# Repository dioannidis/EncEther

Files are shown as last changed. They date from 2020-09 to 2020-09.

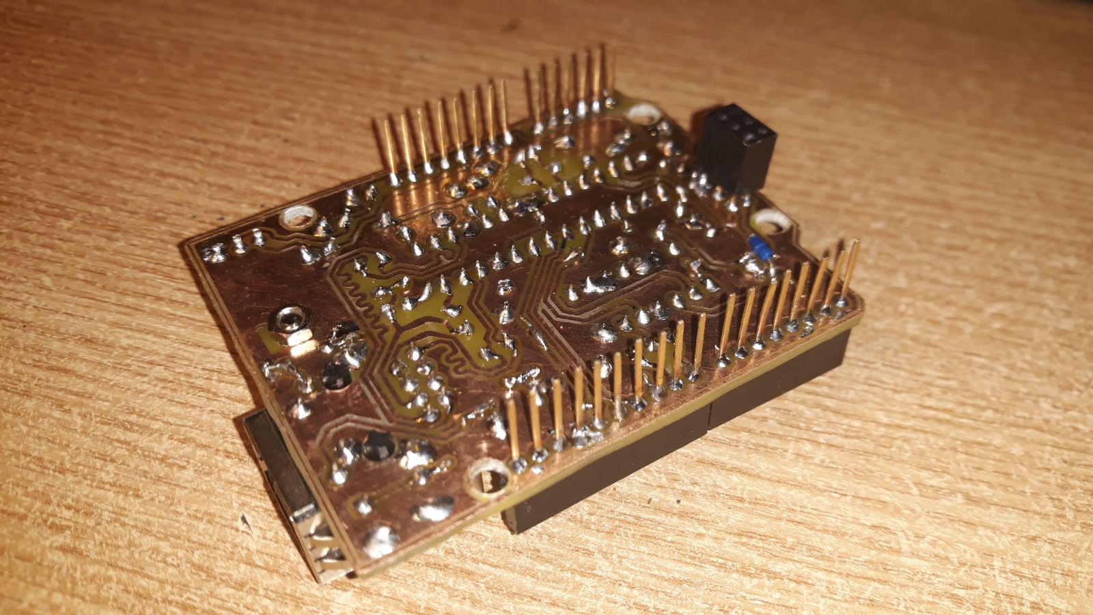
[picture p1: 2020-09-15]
IMAGES/EncEther-v1-bottom.jpg

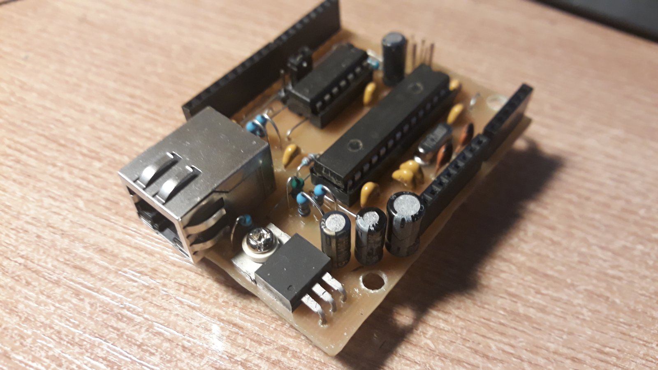
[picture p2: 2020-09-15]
IMAGES/EncEther-v1-top.jpg

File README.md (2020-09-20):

# EncEther

( version 3 )

   A single side, through hole, Arduino ethernet shield, designed in Kicad 5. 



### Main IC's

   * ENC28J60        10Base-T stand-alone ethernet controller
   * SN74HCT125N     3 state quadruple buffer for level shifting

   ( all the components datasheets can be found in the DATASHEETS directory )

### Board Info / Tips

   * As a single side board jumper wires are hard to avoid. Currently, exists 16 jumper wires, which are to be soldered first.
   * The L1 4μH inductor, is for EMC ( as per datasheet ), so you can replace it with a jumper wire.
   * The R3, R4, R11 and R12 are 49.9 Ω 1% 1/4W resistors ( as per datasheet ) but I'm using 51 Ω 1% 1/4W with success. The 49.9 Ω 1% ones are hard to find ( at least I can't find them easily ).
   * Because some jumper wires are routed under the sockets, use precision sockets which have more room under them.
   * The MagJack I use is the LMJTAB881243ML from AMPHENOL. You can find it at [TME](https://www.tme.eu/en/details/lmjtab881243m-l/rj-connectors/amphenol/lmjtab881243ml) or at [Grobotronics](https://grobotronics.com/rj45-ethernet-magjack-compatible.html) ( cheaper ).
   * The wakeup and clkout pins of ENC28J60 are not exposed. As this is an UNO shield, there is no need to provide clock to the MCU, it has it's own. And AFAIK, UIPEthernet doesn't implement the wakeup function.

### Board Configuration 

   * Jumper J3

      The CS/SS ( chip select / slave select ) signal can be connected to Arduino Pin 10 or Pin 9 using the J3 jumper.

         * Jumper on the 1-2 pins connects CS/SS to Arduino Pin 10. ( default )
         * Jumper on the 2-3 pins connects CS/SS to Arduino Pin 9.

      The Interrupt pin from the ENC28J60 it can be connected to Arduino Pin 9 or Pin 8 using the J3 jumper.

         * Jumper on the 3-4 pins connects the ENC28J60's interrupt pin to Arduino Pin 9.
         * Jumper on the 4-5 pins connects the ENC28J60's interrupt pin to Arduino Pin 8.

      Optionally, you can populate the U4 socket with an AT24MAC402-602 on a 8-Pin SOIC to DIP adapter ( something like [this](https://www.sparkfun.com/products/13655) or [this](https://www.adafruit.com/product/1212) ) to have a legit MAC Address and an extra 2Kbit serial EEPROM.

   * Jumper J4

      The I2C address of the AT24MAC402-602 can be selected using Jumper J3 as :
		
         * Jumper on 2-3 pins address is 0. ( default )
         * Jumper on 1-2 pins address is 1.

### Examples

( in EXAMPLES directory. Of course the examples work with any ENC28J60 board / module. )

   * EthernetRest 
	  
      Uses the UIPEthernet and aRest libraries.
	   
      Using the aRest API you can control all digital and analog pins and / or executing custom functions or read custom variables.

### Gallery

   Those pictures are from v1. It didn't have the AT24MAC402-602 option and the CS/SS Pin selection designed yet.




   As you can see in the picture below, the AT24MAC402, is on the small red 8-Pin SOIC to DIP adapter on the breadboard.



-----

Copyright © 2020 Dimitrios Chr. Ioannidis

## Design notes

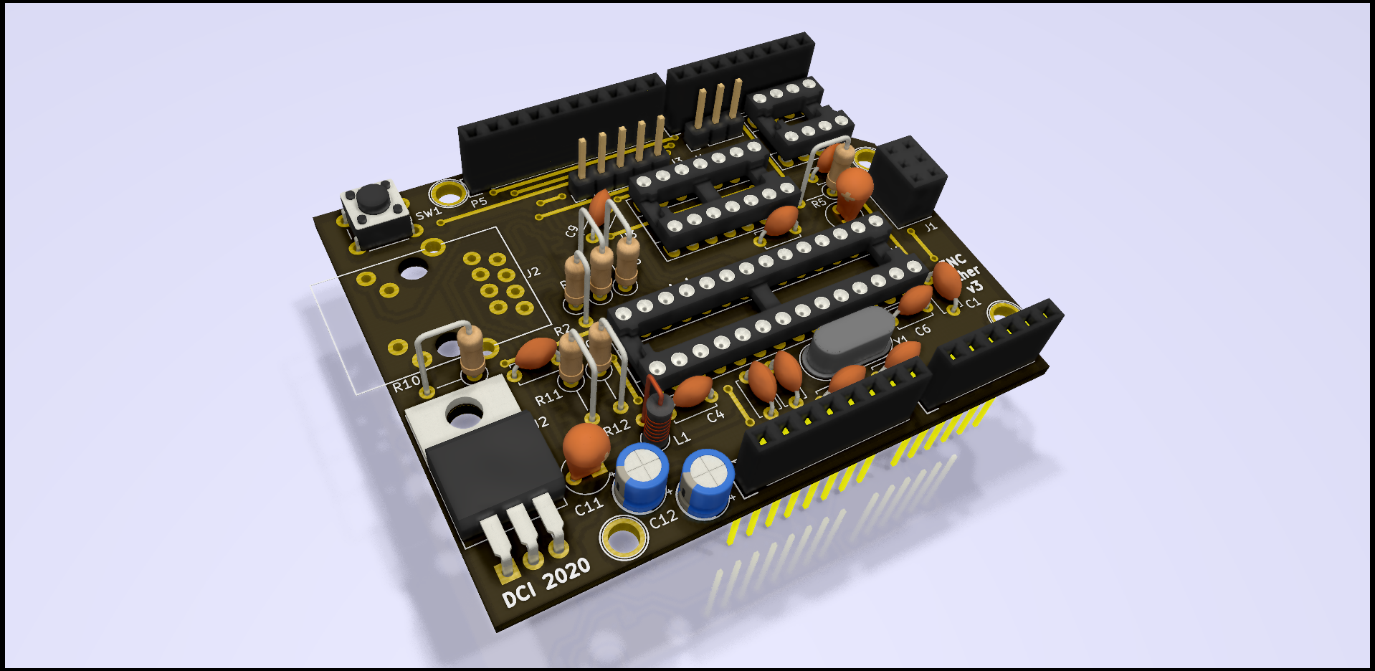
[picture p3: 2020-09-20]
IMAGES/enc28j60_buffered_tht_shield.png

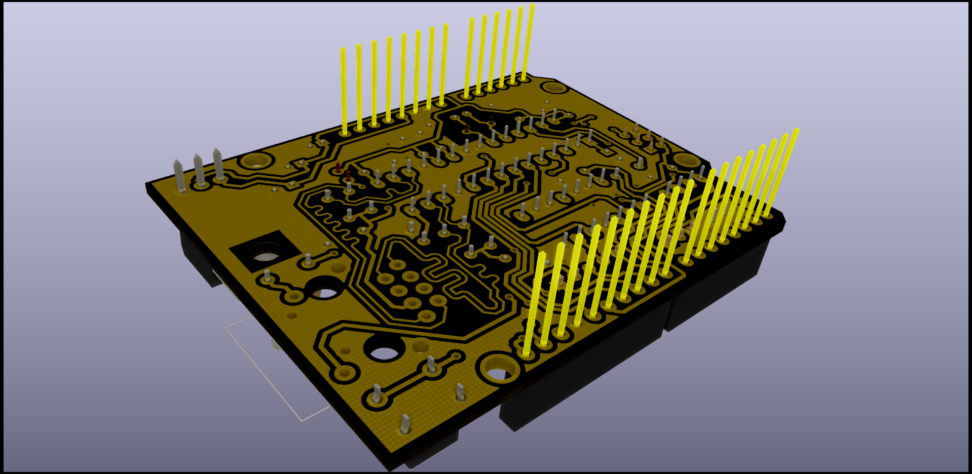
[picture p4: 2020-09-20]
IMAGES/enc28j60_buffered_tht_shield_bottom.png

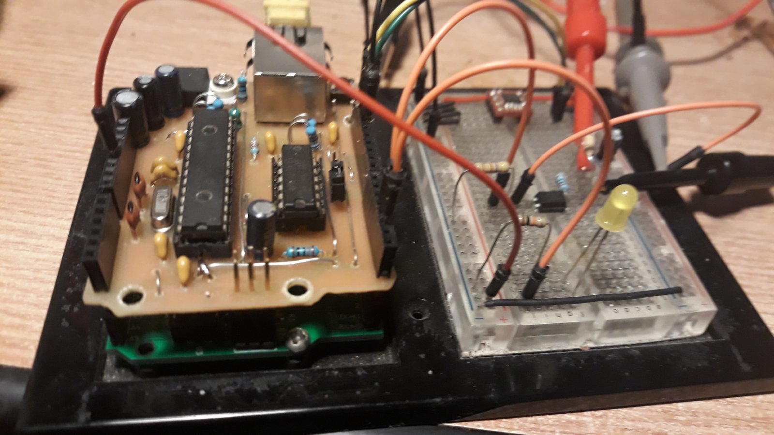
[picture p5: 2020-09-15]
IMAGES/EncEther-v1-uno.jpg

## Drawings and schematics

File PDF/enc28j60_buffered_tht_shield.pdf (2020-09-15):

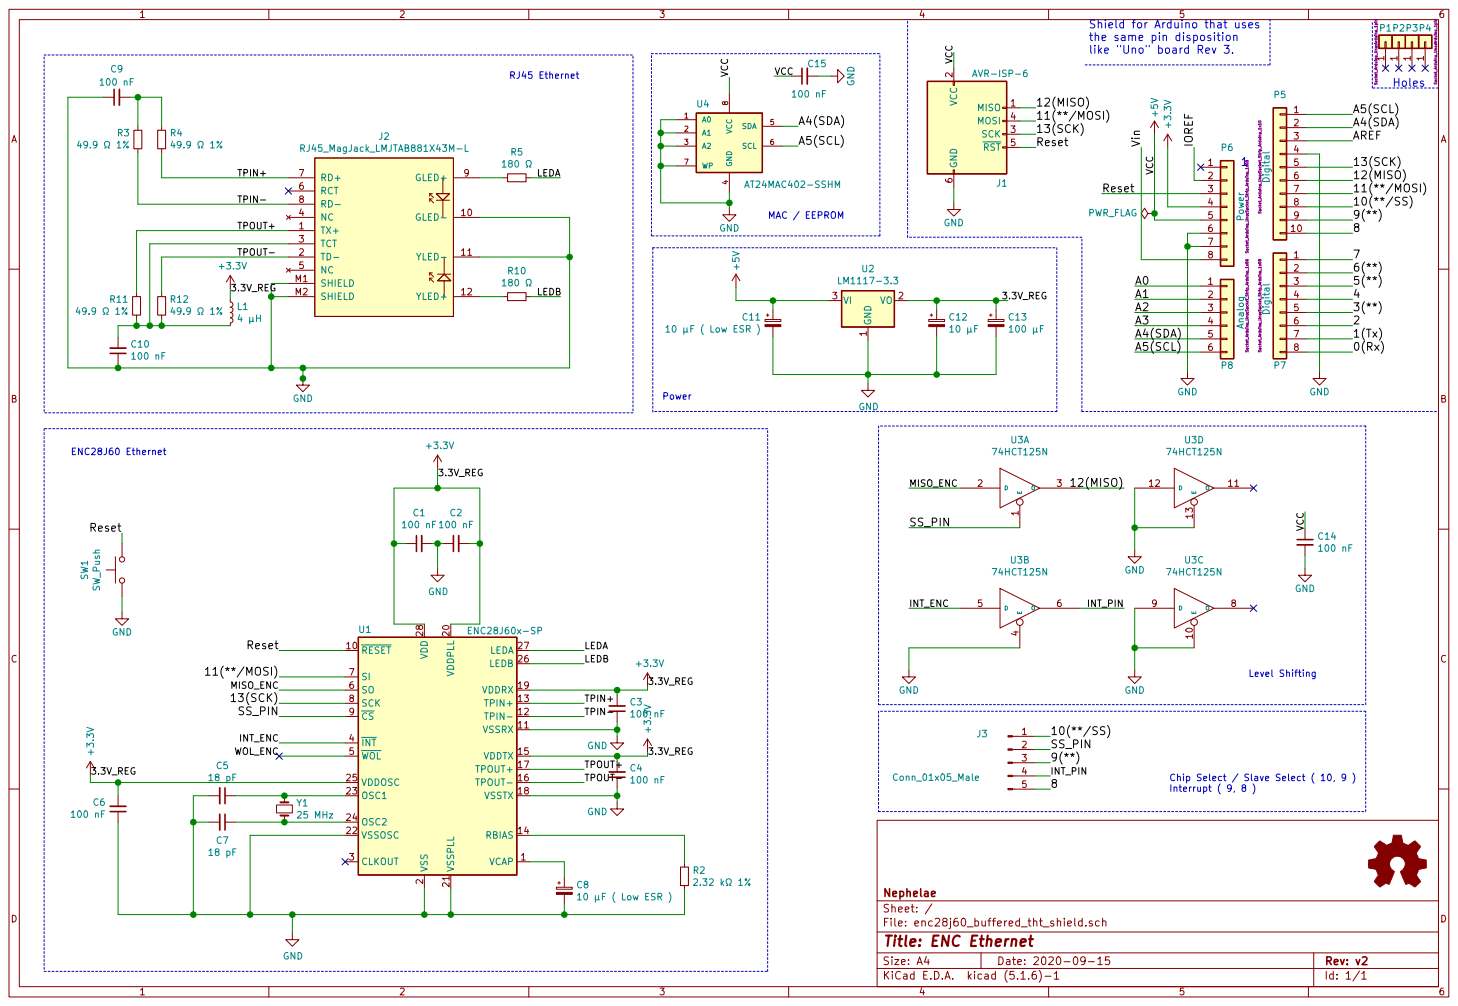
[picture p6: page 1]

the same pin disposition

2 SCK 3 MOSI 4 RST 5 GND

4 SDA 5 SCL 6 WP 7 VCC U4 8 AT24MAC402-SSHM

2 VDDPLL 20 VSSPLL 21 VSSOSC 22 OSC1 23 OSC2 24 VDDOSC 25

Chip Select / Slave Select ( 10, 9 )

Id: 1/1 Title: ENC Ethernet

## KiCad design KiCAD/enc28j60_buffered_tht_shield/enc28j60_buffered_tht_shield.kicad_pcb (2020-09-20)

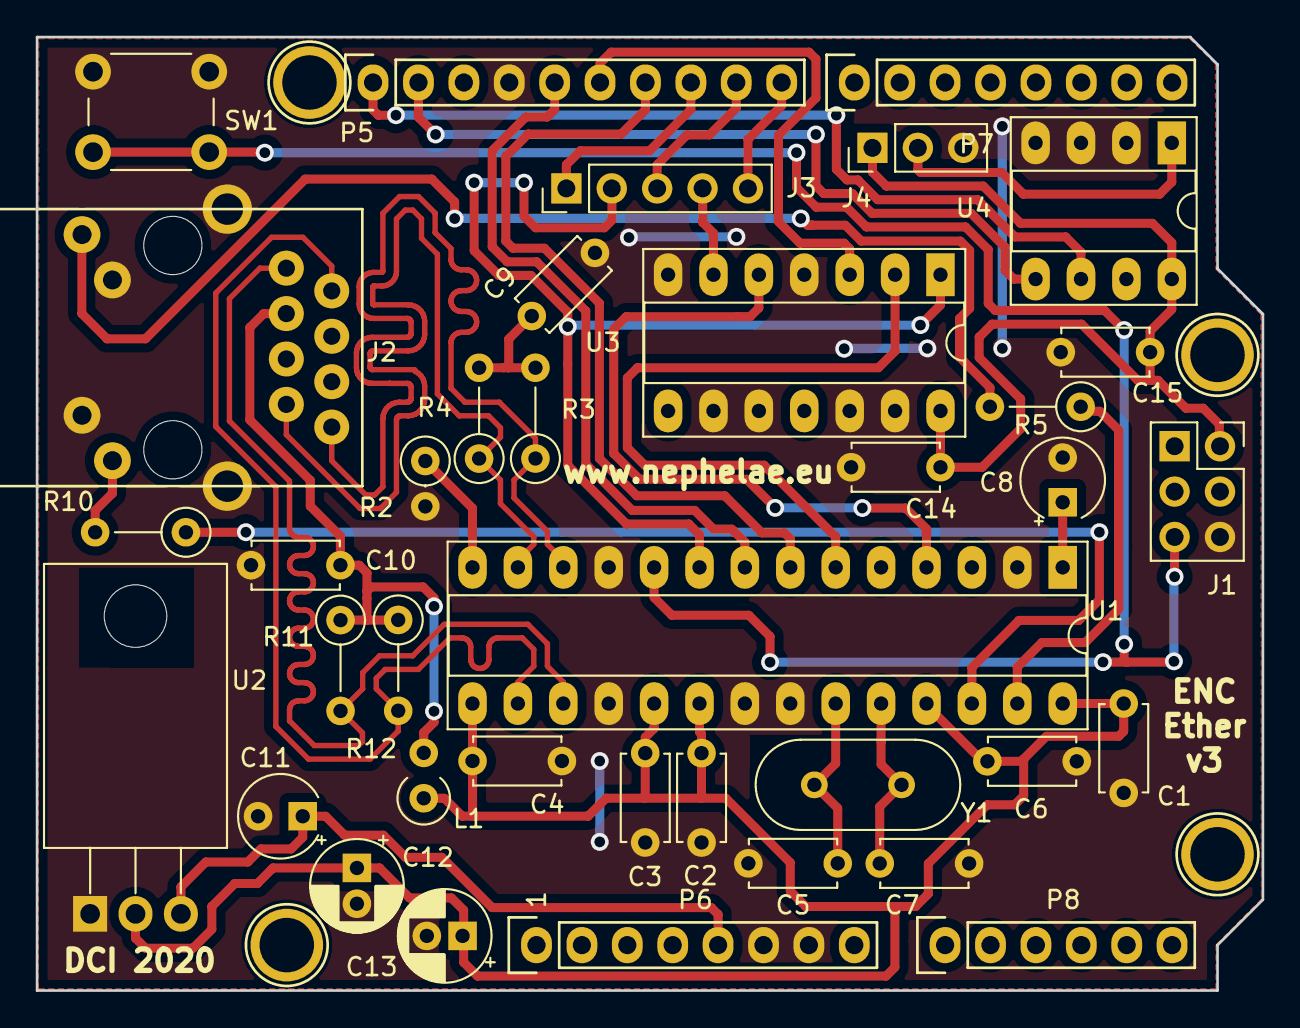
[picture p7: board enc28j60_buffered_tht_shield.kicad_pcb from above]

Board: 2 copper layers, 68.6 x 53.3 mm, 41 parts (0 on the bottom side), 32 nets.

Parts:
C1, C2, C3, C4, C6, C9, C10, C14, C15: 100 nF; C_Disc_D4.7mm_W2.5mm_P5.00mm
C5, C7: 18 pF; C_Disc_D4.7mm_W2.5mm_P5.00mm
C8, C11: 10 μF ( Low ESR ); CP_Radial_Tantal_D4.5mm_P2.50mm
C12: 10 μF; CP_Radial_D5.0mm_P2.00mm
C13: 100 μF; CP_Radial_D5.0mm_P2.00mm
J1: AVR-ISP-6; PinSocket_2x03_P2.54mm_Vertical
J2: RJ45_MagJack_LMJTAB881X43M-L
J3: Conn_01x05_Male; PinHeader_1x05_P2.54mm_Vertical
J4: Conn_01x03_Male; PinHeader_1x03_P2.54mm_Vertical
L1: 4 μH; L_Axial_L6.6mm_D2.7mm_P2.54mm_Vertical_Vishay_IM-2
P1, P2, P3, P4: CONN_01X01; Arduino_1pin
P5: Digital; Socket_Strip_Arduino_1x10
P6: Power; Socket_Strip_Arduino_1x08
P7: Digital; Socket_Strip_Arduino_1x08
P8: Analog; Socket_Strip_Arduino_1x06
R2: 2.32 kΩ 1%; R_Axial_DIN0207_L6.3mm_D2.5mm_P2.54mm_Vertical
R3, R4, R11, R12: 49.9 Ω 1%; R_Axial_DIN0207_L6.3mm_D2.5mm_P5.08mm_Vertical
R5, R10: 180 Ω; R_Axial_DIN0207_L6.3mm_D2.5mm_P5.08mm_Vertical
SW1: SW_Push; SW_PUSH_6mm_H5mm
U1: ENC28J60x-SP; DIP-28_W7.62mm_Socket_LongPads
U2: LM1117-3.3; TO-220-3_Horizontal_TabDown
U3: 74HCT125N; DIP-14_W7.62mm_Socket_LongPads
U4: AT24MAC402-SSHM; DIP-8_W7.62mm_Socket_LongPads
Y1: 25 MHz; Crystal_HC49-4H_Vertical

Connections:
+3V3: C1.1, C2.2, C3.2, C4.2, C6.2, C12.1, C13.1, L1.1, U1.15, U1.19, U1.20, U1.25, U1.28, U2.2
+5V: C11.1, P6.5, U2.3
/8: J3.5, P5.10
/9(**): J3.3, P5.9
/10(**/SS): J3.1, P5.8
/11(**/MOSI): P5.7, U1.7
/12(MISO): P5.6, U3.3
/13(SCK): P5.5, U1.8
/A4(SDA): P5.2, U4.5
/A5(SCL): P5.1, U4.6
/A_A0: J4.2, U4.1
/INT_ENC: U1.4, U3.5
/INT_PIN: J3.4, U3.6
/LEDA: R5.1, U1.27
/LEDB: R10.1, U1.26
/MISO_ENC: U1.6, U3.2
/Reset: J1.5, SW1.2, U1.10
/SS_PIN: J3.2, U1.9, U3.1
/TPIN+: J2.7, R4.1, U1.13
/TPIN-: J2.8, R3.1, U1.12
/TPOUT+: J2.1, R11.2, U1.17
/TPOUT-: J2.2, R12.2, U1.16
GND: C1.2, C2.1, C3.1, C4.1, C5.2, C6.1, C7.2, C8.2, C9.1, C10.1, C11.2, C12.2, C13.2, C14.2, C15.2, J1.6, J2.10, J2.11, J2.M1, J2.M2, J4.3, P5.4, P6.6, P6.7, R2.2, SW1.1, U1.2, U1.11, U1.18, U1.21, U1.22, U2.1, U3.4, U3.7, U3.9, U3.10, U3.12, U3.13, U4.2, U4.3, U4.4
unnamed: C5.1, U1.23, Y1.1
unnamed: C7.1, U1.24, Y1.2
unnamed: C8.1, U1.1
unnamed: C9.2, R3.2, R4.2
unnamed: C10.2, J2.3, L1.2, R11.1, R12.1
unnamed: J2.9, R5.2
unnamed: J2.12, R10.2
unnamed: R2.1, U1.14
VCC: C14.1, C15.1, J1.2, J4.1, U3.14, U4.8

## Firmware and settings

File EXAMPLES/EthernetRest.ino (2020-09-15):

/*
  UIPEthernet and aRest for Arduino UNO example.

  Written in 2020 by Dimitrios Chr. Ioannidis under a GPL license.
*/

// UIPEthernet configuration.

// Edit the <Arduino-Libraries-path>\UIPEthernet\utility\uipethernet-conf.h file
// and change the values as below.

//#define UIP_SOCKET_NUMPACKETS     3
//#define UIP_CONF_MAX_CONNECTIONS  2
//#define UIP_CONF_UDP              1
//#define UIP_CONF_UDP_CONNS        1

#define UIP_CONF_MAX_LISTENPORTS  1
#define UIP_CONF_ARPTAB_SIZE      5
#define UIP_CONF_BUFFER_SIZE      300

// Wire configuration.
#define BUFFER_LENGTH 16

// aREST configuration.
#define LIGHTWEIGHT            0
#define AREST_NUMBER_VARIABLES 0
#define AREST_NUMBER_FUNCTIONS 2
//#define DEBUG_MODE             1

#define ethernet_h_   // For aRest to work with UIPEthernet

// Libraries

#include <UIPEthernet.h>
#include <ethernet_comp.h>
#include <Wire.h>
#include <aREST.h>
#include <avr/wdt.h>

// aREST.h
#define NAME_SIZE     5
#define ID_SIZE       4

// Ethernet server
EthernetServer server(80);

#define pwmPin   3    // The PWM output 
#define relayPin 5    // The Relay
#define ledPin   2

// Create aREST instance
aREST rest = aREST();

// Variables to be exposed to the API
//int temperature;
//int humidity;

// Declare functions to be exposed to the API
int pwmControl(String command);

void setup(void)
{
  //  In case for Opto
  //  digitalWrite(relayPin, HIGH);  //Set pin to OUTPUT to SINK any current
  digitalWrite(relayPin, LOW);

  pinMode(relayPin, OUTPUT);
  pinMode(pwmPin, OUTPUT);       // Pin 3 , PWM 490 Hz

  // Give name & ID to the device (ID should be 6 characters long)
  rest.set_id(F("EncE"));
  rest.set_name(F("001"));
  rest.set_status_led(ledPin);

  // Start Serial
  Serial.begin(9600);

  // Start I2C communication
  Wire.begin();
  Wire.setClock(400000);

  // Enter a MAC address for your controller below.
  byte mac[] = { 0x90, 0xA2, 0xDA, 0x0E, 0xFE, 0x41 };

  // If you have connected a AT24MAC402 uncomment the following
  // to read the MAC address parts from the EEPROM into mymac
  
  // readMacAddress(0x0, mac);

  // Init variables and expose them to REST API
  //  temperature = 24;
  //  humidity = 40;
  //  rest.variable("temperature",&temperature);
  //  rest.variable("humidity",&humidity);

  // Function to be exposed
  rest.function("pwm", pwmControl);

  // Start the Ethernet connection and the server
  if (Ethernet.begin(mac) == 0) {
    Serial.println(F("Failed to configure Ethernet using DHCP"));
  }

  server.begin();

  // Display the MAC ADDRESS
  Serial.print(F("MAC : "));
  for (byte i = 0; i < 6; ++i) {
    Serial.print(mac[i], HEX);
    if (i < 5)
      Serial.print(F(":"));
  }
  Serial.println();
  
  Serial.print(F("IP : "));
  Serial.println(Ethernet.localIP());

  // Start watchdog
  wdt_enable(WDTO_4S);
}

void loop() {

  // listen for incoming clients
  EthernetClient client = server.available();
  rest.handle(client);
  
  // Uncomment the following line
  // if you have connected a led in ledPin
  
  //rest.glow_led();
    
  Ethernet.maintain();
  wdt_reset();

}

// Custom function accessible by the API
int pwmControl(String command) {

  // Get state from command
  int state = command.toInt();

  if (state > -1 && state < 255) {
    analogWrite(pwmPin, state);
    return 1;
  }
  
  return 0;
}

// Function to read the MAC address from a AT24MAC402 EEPROM
//
// address: the 3-bit address assinged to the EEPROM (using the A0 A1 A2 pins)
// macaddr: a pointer to 6 bytes of memory
//
void readMacAddress(byte address, byte macaddr[]) {

  // Tell the EEPROM where we would like to read from
  Wire.beginTransmission(0x58 | address);
  Wire.write(0x9A); // Location of the EUI-48
  Wire.endTransmission();

  // Now read 6 bytes from that memory address
  Wire.requestFrom(0x58 | address, 6);
  for (byte i = 0; i < 6; i++) {
    macaddr[i] = Wire.read();
  }

}

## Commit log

2020-09-03 Revision 1. 74HCT125N LM1117 3.3 ENC28J60
    [enc28j60_buffered_tht_shield.kicad_pcb, enc28j60_buffered_tht_shield.sch]
2020-09-12 Fixed AVR-ISP-PINS
    [enc28j60_buffered_tht_shield.kicad_pcb, enc28j60_buffered_tht_shield.sch]
2020-09-13 Added LM117 DataSheet
    [enc28j60_buffered_tht_shield.kicad_pcb]
2020-09-13 Added Socket Arduino 3D Paths for preview.
    [enc28j60_buffered_tht_shield.kicad_pcb]
2020-09-14 Added AT24MAC402-602 as an option.
    [enc28j60_buffered_tht_shield.kicad_pcb, enc28j60_buffered_tht_shield.sch]
2020-09-14 Images and misc.
    [enc28j60_buffered_tht_shield.kicad_pcb, enc28j60_buffered_tht_shield.sch]
2020-09-14 Final ( ? ) v2
    [enc28j60_buffered_tht_shield.kicad_pcb, enc28j60_buffered_tht_shield.sch]
2020-09-14 Some changes to ground plane.
    [enc28j60_buffered_tht_shield.kicad_pcb]
2020-09-15 Added pictures of the v1 home made prototype.
2020-09-15 Initial commit.
    [enc28j60_buffered_tht_shield.kicad_pcb, enc28j60_buffered_tht_shield.sch]
2020-09-20 Fix ethernet differential pair length, skew. Fix LMJTAB881X43M Ground Pin. Added jumper for I2C address selection.
    [enc28j60_buffered_tht_shield.kicad_pcb, enc28j60_buffered_tht_shield.sch]
2020-09-20 Τrying to impedance to 50 Ω
    [enc28j60_buffered_tht_shield.kicad_pcb]
2020-09-20 Fix library problem.
    [enc28j60_buffered_tht_shield.kicad_pcb, enc28j60_buffered_tht_shield.sch]
